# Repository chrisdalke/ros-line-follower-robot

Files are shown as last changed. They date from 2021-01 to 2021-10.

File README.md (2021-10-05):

# ROS Line Following Robot

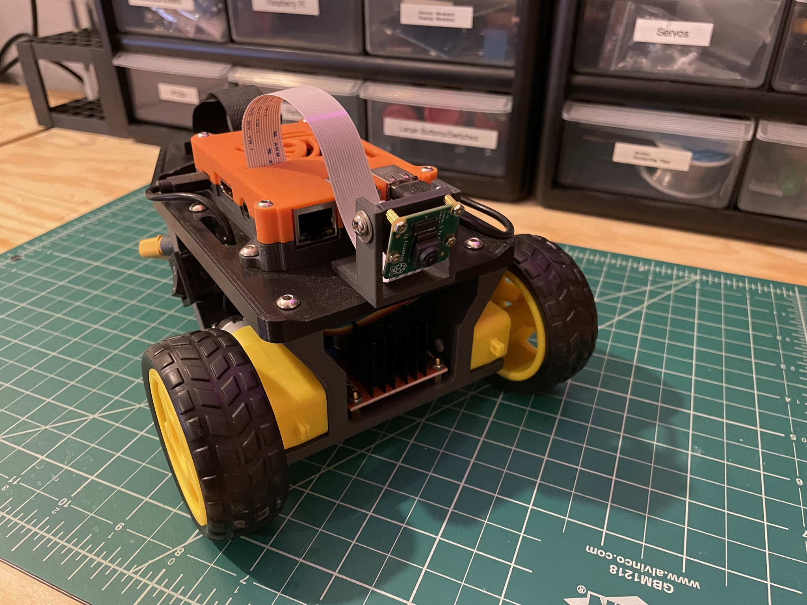
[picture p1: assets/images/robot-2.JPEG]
Line Follower Robot


This project is a small line-following robot. It can detect and follow tape lines on my floor! 
The robot runs ROS on a Raspberry Pi, uses OpenCV to detect lines, and an Arduino Pro Micro to control
differential steering.

I built this small project to sharpen my ROS and OpenCV skills. Your mileage may vary; the OpenCV code
likely will not work in a different lighting environment. The perception system won't generalize since it relies on the line being significantly _lighter_ than the floor, which works in my workspace.

Check out the robot in action at https://www.youtube.com/watch?v=0DcV46YkHR8.

## Architecture

```
┌────────────────────────────────┐ ┌─────────────────────────────────────────────────────────┐
│ ROBOT HARDWARE                 │ │ ROS NODES                                               │
│ ┌──────────────┐ Raw           │ │ ┌────────────────────────┐ Processed ┌────────────────┐ │
│ │ Raspberry Pi │ Image         │ │ │ Image Preparation      │ Image     │ Line Detection │ │
│ │    Camera    ├───────────────┼─┼─► Threshold,             ├───────────► Path Planning  │ │
│ └──────────────┘               │ │ │ Perspective-Correction │           └───────┬────────┘ │
│                                │ │ └────────────────────────┘                   │          │
│ ┌──────────────┐ Speed/Angle   │ │                                              │          │
│ │ Arduino Pro  │ Command       │ │ ┌────────────────────────┐  Speed/Angle      │          │
│ │ Micro        ◄───────────────┼─┼─┤ Serial Communication   │  Command          │          │
│ └──────┬───────┘               │ │ │ Node                   ◄───────────────────┘          │
│        │ Motor                 │ │ └────────────────────────┘                              │
│        │ Command               │ │                                                         │
│ ┌──────▼─────────────────┐     │ └─────────────────────────────────────────────────────────┘
│ │       Dual Motor       │     │
│ │       Controller       │     │
│ └─────┬────────────┬─────┘     │
│       │            │           │
│ ┌─────▼────┐ ┌─────▼─────┐     │
│ │Left Motor│ │Right Motor│     │
│ └──────────┘ └───────────┘     │
│                                │
└────────────────────────────────┘
```
The robot architecture is a unidirectional pipeline. First, sensor data is fed from the Raspberry Pi camera, and through image processing which performs a perspective correction and contrast/threshold image adjustment to facilitate line detection.

Once the image is processed, a line detection algorithm is run to find the approximate direction of the line to follow.
The code uses the relative position and angle of the line to compute a target speed/angle that will track the line.

The control data is sent over a serial connection to an Arduino Pro Micro, which computes individual motor commands and commands a dual motor controller.

## Development Notes

### Prerequisites
To run this project, you must have a ROS Noetic installation setup on a Raspberry Pi. This repository should be checked out into a Catkin workspace. For more information, see the [ROS Tutorials](http://wiki.ros.org/ROS/Tutorials).

You must also have the following dependencies installed: 
- Python 3 (`sudo apt install python3.8 && sudo apt install python3-pip`)
- OpenCV (`pip install opencv-python`)
- CvBridge (`sudo apt install ros-noetic-cv-bridge`)
- PySerial (`pip install pyserial`)
- numpy (`pip install numpy`)
- rosserial_python (`sudo apt install ros-noetic-rosserial-python`)
- robot_upstart (`sudo apt install ros-noetic-robot-upstart`)
- video_stream_opencv (`sudo apt install ros-noetic-video-stream-opencv`)
- raspicam_node (See https://github.com/UbiquityRobotics/raspicam_node for build/install instructions)

### Starting the Project
To run the entire project, use the roslaunch file in this repository:
`roslaunch line_follower line_follower.launch`

### Remote ROS

To connect to the remote ROS instance, set the following environment variables:
```
export ROS_MASTER_URI=http://linefollower:11311
export ROS_IP=linefollower
```

Start the visualization:
```
rosrun rviz rviz -d ~/linefollower/catkin_ws/src/ros-line-follower-robot/rviz/line_follower.rviz
```

### Starting/Stopping the Background Service

The entire stack can be launched in the background using `robot_upstart`.

To install the background service:
```
rosrun 
    robot_upstart install 
    --job linefollower
    --setup /home/ubuntu/catkin_ws/devel/setup.sh
    --logdir /var/log/upstart
    --symlink line_follower/launch/line_follower.launch
sudo systemctl daemon-reload
```

To start the background service:
```
sudo systemctl enable linefollower
sudo systemctl start linefollower
```

To stop the background service:
```
sudo systemctl stop linefollower
sudo systemctl disable linefollower
```

### Topics

- `/camera/raspicam_node/image`: An image from the Raspberry Pi camera.
- `/camera/raspicam_node/image`: A mockup video published on a loop, used to test the CV pipeline.
- `/line_follower/processed_image`: The processed image: threshold, reverse perspective transform.
- `/motor_driver/speed`: A commanded speed for the Arduino to achieve.
- `/motor_driver/direction`: A commanded direction for the Arduino to achieve.

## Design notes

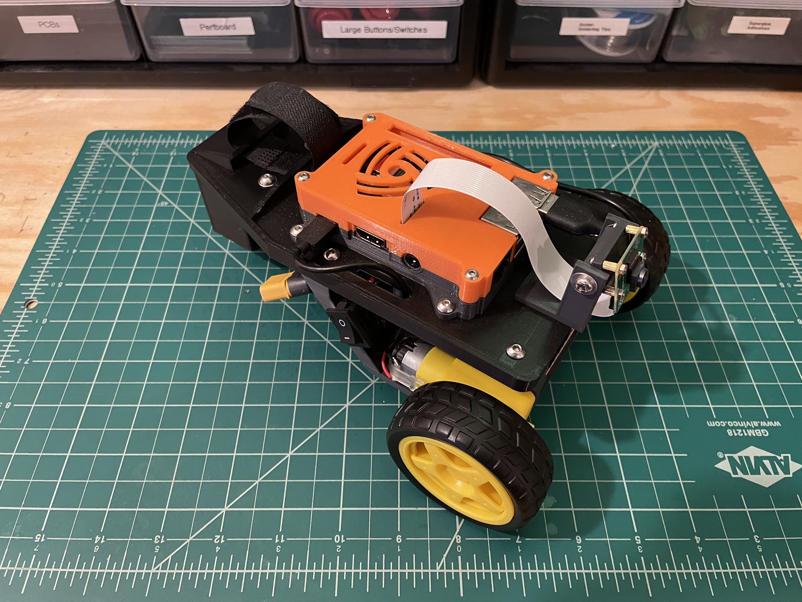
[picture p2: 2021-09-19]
assets/images/robot-1.JPEG

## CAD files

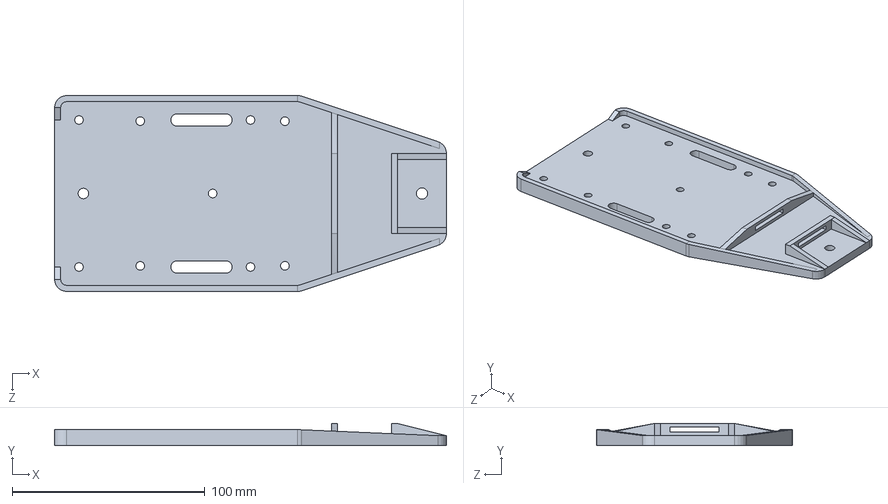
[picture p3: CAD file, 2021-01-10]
cad/Base Tier 1.SLDPRT
203.2 x 11.4 x 101.6 mm

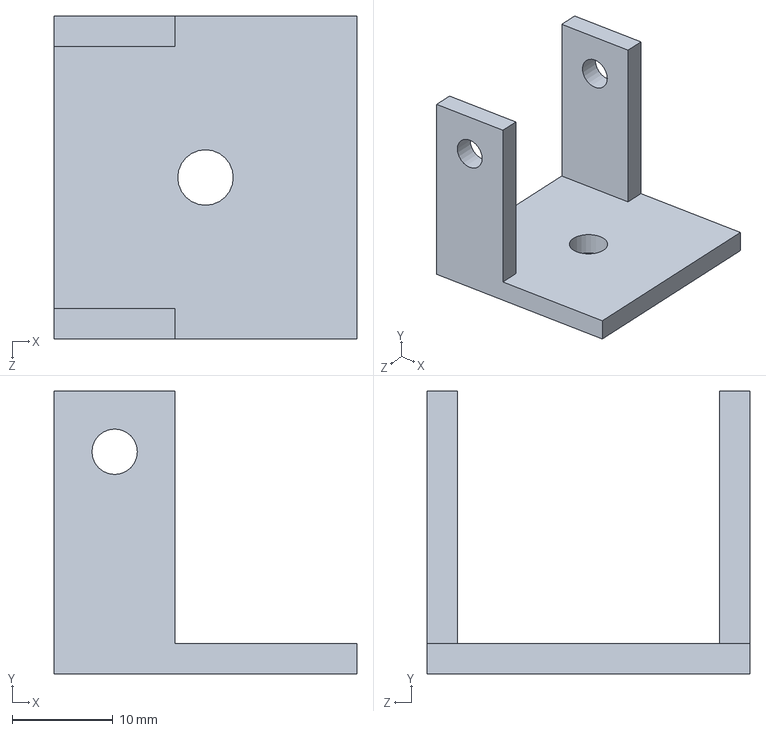
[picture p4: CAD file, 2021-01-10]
cad/RPI Camera Swivel.SLDPRT
30.0 x 28.0 x 32.0 mm

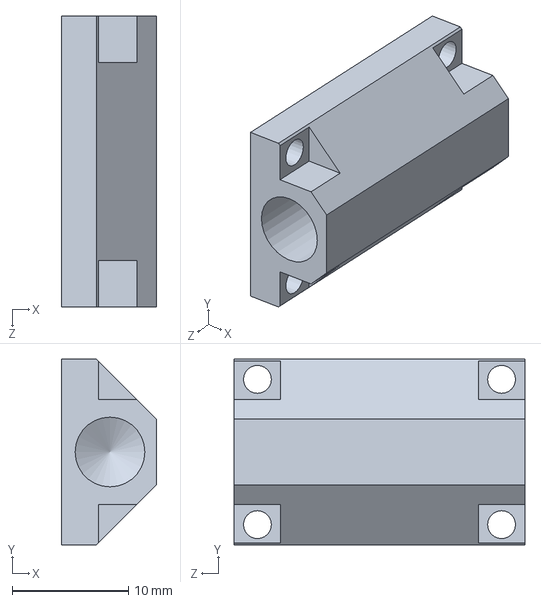
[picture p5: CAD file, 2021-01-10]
cad/RPI Camera Mount.SLDPRT
8.17 x 16.0 x 25.0 mm

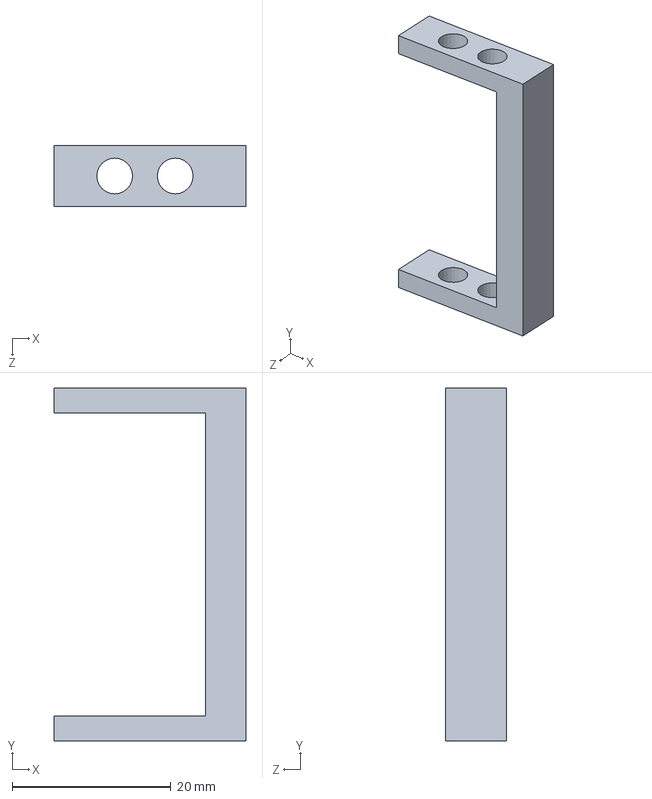
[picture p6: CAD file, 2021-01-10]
cad/Tier Spacer.SLDPRT
24.1 x 44.5 x 7.62 mm

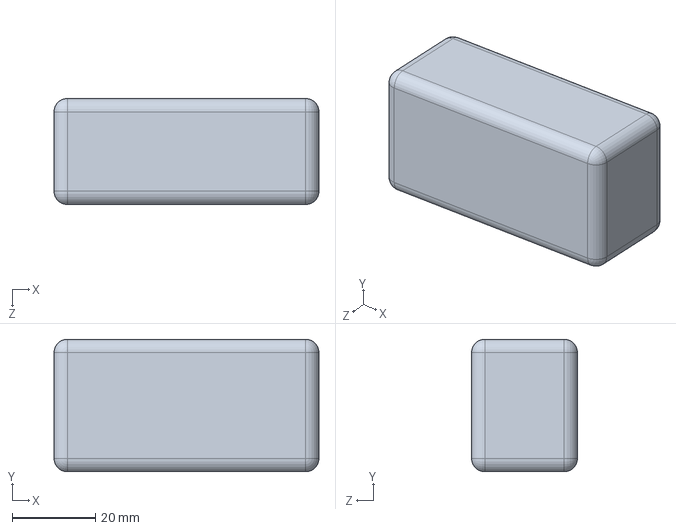
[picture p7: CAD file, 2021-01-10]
cad/LiPo Mockup.SLDPRT
63.5 x 31.8 x 25.4 mm

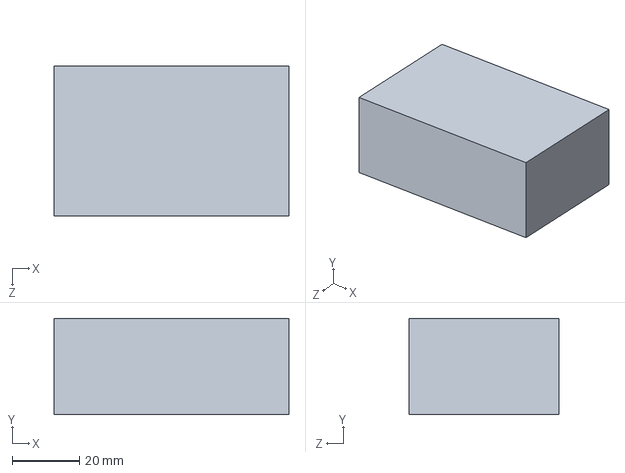
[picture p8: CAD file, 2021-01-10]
cad/PSU Mockup.SLDPRT
69.8 x 28.6 x 44.5 mm

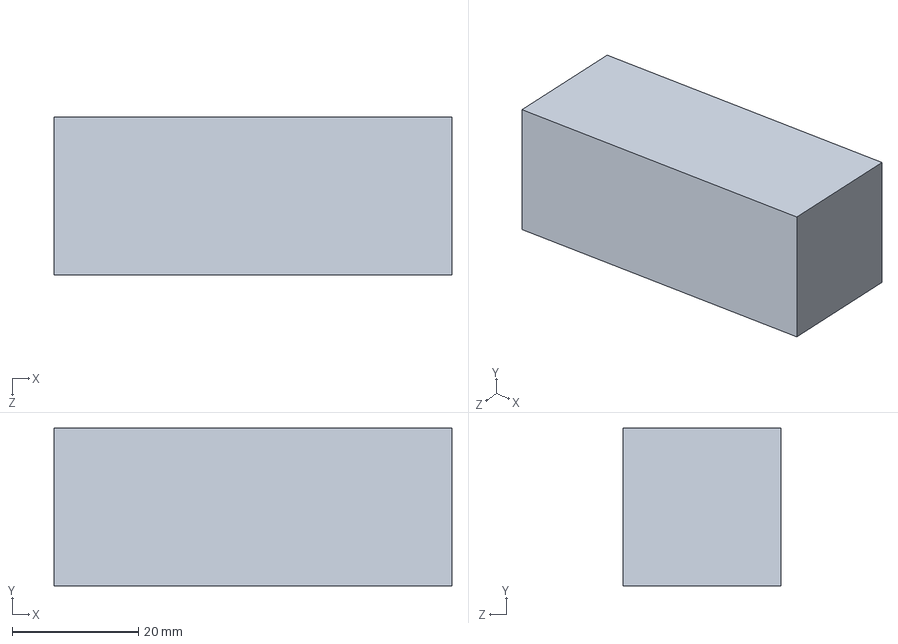
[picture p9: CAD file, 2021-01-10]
cad/Spacer.SLDPRT
63.0 x 25.0 x 25.0 mm

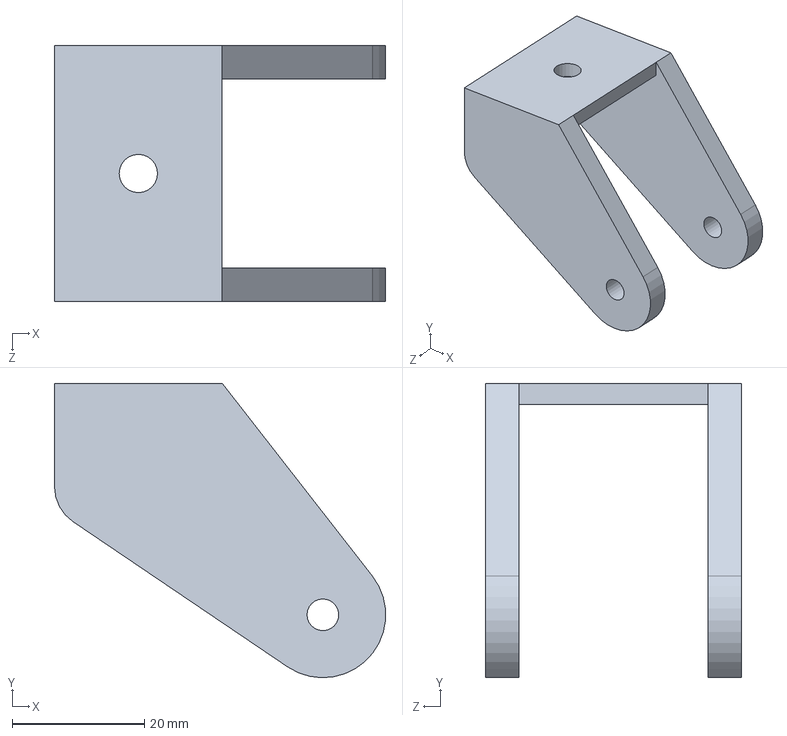
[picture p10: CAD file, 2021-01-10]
cad/Caster Wheel.SLDPRT
50.1 x 44.6 x 38.7 mm

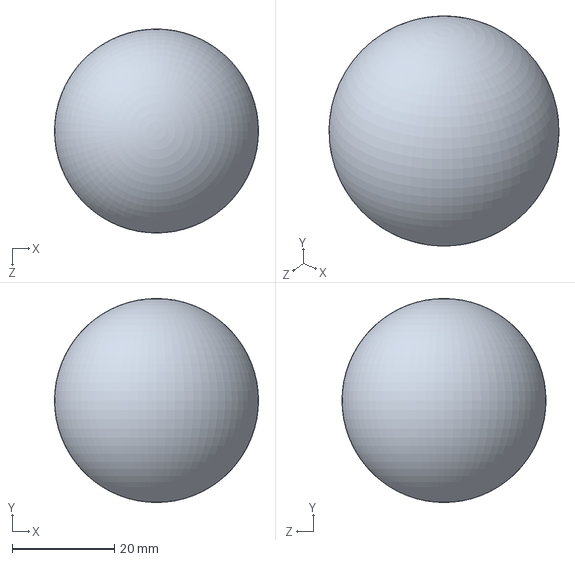
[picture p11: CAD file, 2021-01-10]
cad/Pong Ball.SLDPRT
40.0 x 40.0 x 40.0 mm

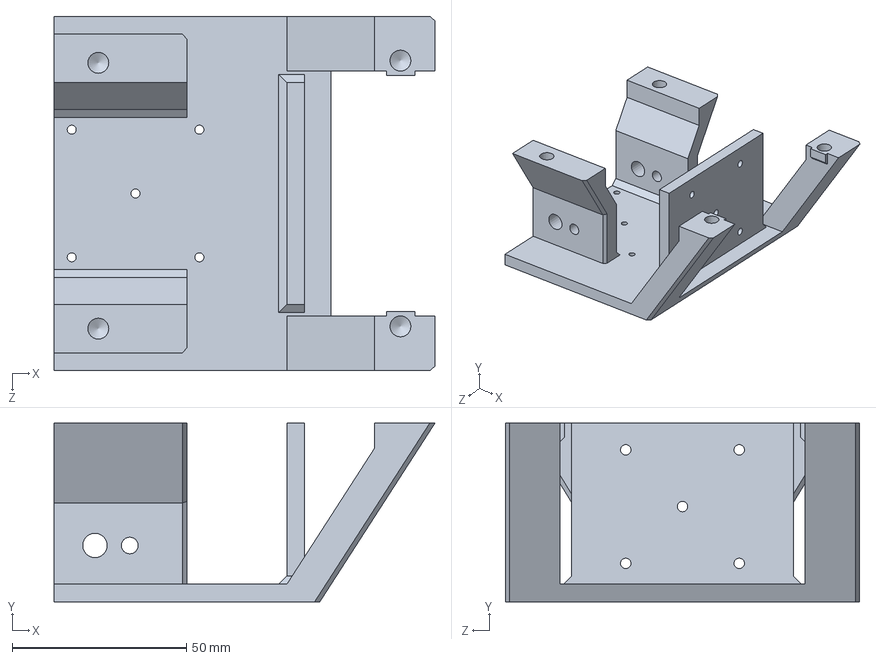
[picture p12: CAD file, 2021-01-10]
cad/Base Tier 2.SLDPRT
109.2 x 51.2 x 101.6 mm

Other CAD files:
cad/Base Tier 1.STL
cad/Base Tier 2.STL
cad/Caster Wheel.STL
cad/RPI Camera Mount.STL
cad/RPI Camera Swivel.STL

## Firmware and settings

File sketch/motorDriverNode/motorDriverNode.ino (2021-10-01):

int leftMotorEnablePin = 5;
int leftMotorDirPin1 = 16;
int leftMotorDirPin2 = 10;
int rightMotorEnablePin = 6;
int rightMotorDirPin1 = 8;
int rightMotorDirPin2 = 7;
unsigned long lastMsg = 0;
unsigned long lastCooldown = 0;

bool hasTarget = false;
float targetSpeed = 0;
float targetDirection = 0;
float tempDirRad = 0;

const byte numChars = 64;
char receivedChars[numChars];

String speedKey = "s=";
String dirKey = "d=";


void setup() {
  pinMode(leftMotorEnablePin, OUTPUT);
  pinMode(leftMotorDirPin1, OUTPUT);
  pinMode(leftMotorDirPin2, OUTPUT);
  pinMode(rightMotorEnablePin, OUTPUT);
  pinMode(rightMotorDirPin1, OUTPUT);
  pinMode(rightMotorDirPin2, OUTPUT);
  Serial.begin(115200);
}

// Write -1 -> 1 as a motor speed
void writeLeftMotor(float scaledSpeed) {
  if (scaledSpeed < 0) {
    digitalWrite(leftMotorDirPin1, HIGH);
    digitalWrite(leftMotorDirPin2, LOW);
  } else {
    digitalWrite(leftMotorDirPin1, LOW);
    digitalWrite(leftMotorDirPin2, HIGH);
  }
  analogWrite(leftMotorEnablePin, abs(scaledSpeed) * 255);
}
void writeRightMotor(float scaledSpeed) {
  if (scaledSpeed < 0) {
    digitalWrite(rightMotorDirPin1, HIGH);
    digitalWrite(rightMotorDirPin2, LOW);
  } else {
    digitalWrite(rightMotorDirPin1, LOW);
    digitalWrite(rightMotorDirPin2, HIGH);
  }
  analogWrite(rightMotorEnablePin, abs(scaledSpeed * 4) * 255);
}


void loop() {
  // Parse serial stream for speed and direction assignments
  bool newData = false;
  char currentChar;
  static byte bufferIndex = 0;
  while (Serial.available() > 0 && newData == false) {
    currentChar = Serial.read();
    if (currentChar != '\n') {
      receivedChars[bufferIndex++] = currentChar;
      if (bufferIndex >= numChars) {
          bufferIndex = numChars - 1;
      }
    } else {
      receivedChars[bufferIndex++] = '\0';
      bufferIndex = 0;
      newData = true;
    }
  }
  if (newData) {
    String keyValue =String(receivedChars);
    if (keyValue.startsWith(speedKey)) {
      targetSpeed = keyValue.substring(speedKey.length()).toFloat();
      lastMsg = millis();
    }
    if (keyValue.startsWith(dirKey)) {
      targetDirection = keyValue.substring(dirKey.length()).toFloat();
      lastMsg = millis();
    }
  }
        
  float leftSpeed = 0.0;
  float rightSpeed = 0.0;

  // Speed and direction should both be [-1, 1]
  // Speed: full backwards to full forwards
  // Direction: full turn left, center, full turn right
  float dirAngleRad = ((targetDirection * 90.0) * 71.0) / 4068.0;
  if (dirAngleRad < 0) {
    leftSpeed = cos(dirAngleRad * 2.0);
    rightSpeed = 1.0;
  } else {
    leftSpeed = 1.0;
    rightSpeed = cos(dirAngleRad * 2.0);
  }
  leftSpeed *= targetSpeed;
  rightSpeed *= targetSpeed;

  // Write the motor values and then immediately do a cooldown for a while
  /*if (millis() - lastCooldown < 200) {
    writeLeftMotor(leftSpeed);
    writeRightMotor(rightSpeed * -1.0);
  } else {
    writeLeftMotor(0);
    writeRightMotor(0);
  }
  if (millis() - lastCooldown > 2000) {
    lastCooldown = millis();
  }*/
  writeLeftMotor(leftSpeed);
  writeRightMotor(rightSpeed * -1.0);

  if (millis() - lastMsg > 1000) {
    targetSpeed = 0.0;
  }
}

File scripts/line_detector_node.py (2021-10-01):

import rospy
import sys
import cv2
import traceback
import numpy as np
from cv_bridge import CvBridge, CvBridgeError
from sensor_msgs.msg import Image
from sensor_msgs.msg import CompressedImage
from std_msgs.msg import Float32

class LineDetector:
    def __init__(self):
        print("Initializing line detector node")
        # read rate config
        self.rate = rospy.Rate(rospy.get_param("/rate/lineDetector")) 
        self.speed = rospy.get_param("speed")
        self.steer_multiplier = rospy.get_param("steering_multiplier")
        self.steer_slowdown_amount = rospy.get_param("steering_slowdown")
        self.image_sub_rpi = rospy.Subscriber("/raspicam_node/image/compressed", CompressedImage, self.image_callback_compressed)
        self.image_sub = rospy.Subscriber("/camera/image_raw", Image, self.image_callback_raw)
        self.image_pub = rospy.Publisher("processed_image", Image)
        self.speed_pub = rospy.Publisher('/motor_driver/speed', Float32)
        self.dir_pub = rospy.Publisher('/motor_driver/direction', Float32)
        self.bridge = CvBridge()
        self.line_offset = 0

    def image_callback_raw(self, msg):
        try:
            cv_image = self.bridge.imgmsg_to_cv2(msg, "passthrough")
            self.process_image(cv_image)
        except Exception as e:
            traceback.print_exc()
            rospy.logerr(e)
            rospy.logerr("CvBridge Error, skipped image frame!")

    def image_callback_compressed(self, msg):
        try:
            np_arr = np.fromstring(msg.data, np.uint8)
            image_np = cv2.imdecode(np_arr, cv2.IMREAD_COLOR)
            self.process_image(image_np)
        except Exception as e:
            rospy.logerr(e)
            rospy.logerr("skipped processed image frame!")

    def process_image(self, cv_image):
        # Downscale to 256x256
        cv_image = cv2.resize(cv_image, (256, 256), interpolation = cv2.INTER_AREA)

        # Change to grayscale and blur a bit
        cv_image = cv2.cvtColor(cv_image, cv2.COLOR_BGR2GRAY)
        cv_image = cv2.GaussianBlur(cv_image, (7, 7), 0)

        # Threshold the image
        (T, threshold_image) = cv2.threshold(cv_image, 180, 255, cv2.THRESH_BINARY)

        # Overlay black box on top of image
        cv2.rectangle(threshold_image, (0, 0), (256, 128), (0,0,0), -1)

        # Get center of the thresholded image
        M = cv2.moments(threshold_image)

        # calculate x,y coordinate of center
        cX = 128
        cY = 128
        if M["m00"] != 0:
            cX = int(M["m10"] / M["m00"])
            cY = int(M["m01"] / M["m00"])

        # Compute an offset in [-1, 1] coordinates to convert to steering
        self.line_offset = (cX - 128.0) / 128.0

        # Change from grayscale
        threshold_image = cv2.cvtColor(threshold_image, cv2.COLOR_GRAY2RGB)

        # Overlay black box on top of image
        cv2.rectangle(threshold_image, (0, 200), (256, 200), (255, 255, 255), -1)
        
        #Center of bottom section
        threshold_image = cv2.circle(threshold_image, (cX, cY), 5, (0, 255, 0), -1)

        # The centerline of the image
        threshold_image = cv2.line(threshold_image,(128,0),(128,256),(0,0,255),1)

        # Bottom quadrant that is used to signal which direction to go
        threshold_image = cv2.line(threshold_image,(0,200),(256,200),(0,0,255),1)

        # visualize line offset
        threshold_image = cv2.line(threshold_image,(int(128 + (self.line_offset * 128)),0),(int(128 + (self.line_offset * 128)),256),(255,0,255),1)

        # Output the processed message
        image_message = self.bridge.cv2_to_imgmsg(threshold_image, "passthrough")
        self.image_pub.publish(image_message)

        # Output the control speed / direction
        self.dir_target = self.line_offset * self.steer_multiplier
        self.dir_slowdown = 1.0 - (abs(self.dir_target) * self.steer_slowdown_amount)
        self.speed_pub.publish(self.speed * self.dir_slowdown)
        self.dir_pub.publish(self.dir_target)

    def run(self):
        while not rospy.is_shutdown():
            self.rate.sleep()

if __name__ =='__main__':
    rospy.init_node('line_detector')
    line_detector = LineDetector()
    #line_detector.run()
    rospy.spin()

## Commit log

2021-01-10 Add CAD files
    [Base Tier 1.SLDPRT, Base Tier 1.STL, Base Tier 2.SLDPRT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]
2021-01-10 Movement control panel, add socket connection to robot streaming via TelemetryJet CLI
2021-01-10 Add websocket control connection, arduino sketch, update solidworks parts
    [Base Tier 1.SLDPRT]
2021-01-11 Add camera livestream image
2021-09-19 Move around folder structure
    [Base Tier 1.SLDPRT, Base Tier 1.STL, Base Tier 2.SLDPRT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]
2021-09-19 Update camera configuration
2021-09-19 Working on motor driver node
2021-09-29 Update motor driver config files, launch file
    [motor_driver_config.yaml]
2021-09-29 Fix motor drive node imports
    [motor_driver_node.py]
2021-09-29 Fix imports, round 2
    [motor_driver_node.py]
2021-09-29 Fix motor driver initialization
    [motor_driver_node.py]
2021-09-29 Update arduino sketch to calculate speeds based on normalized -1,1 scale
2021-09-29 Update motor driver node to fix minor errors
    [motor_driver_node.py]
2021-09-29 Fix error in serial initialization code
    [motor_driver_node.py]
2021-09-29 Experimenting with reducing lag to motor controller
2021-10-01 Add separate subscriber for real RPI camera iamge
2021-10-01 Fix pipeline for images on rpi
    [line_detector_node.py]
2021-10-01 Cut off top half of image, reduce threshold
2021-10-01 Tweak steering and speed rates
2021-10-01 Remove delay in arduino control loop, tweak line detector main loop
